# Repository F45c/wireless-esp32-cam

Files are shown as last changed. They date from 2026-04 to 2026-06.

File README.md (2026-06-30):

# Wireless Esp32-Camera using nRF24l01+

### What is it?

I'm building a wireless esp32 camera that uses the 2.4 GHZ RF chip nRF24l01+ to transmit the images over a greater distance than just WIFI. Using the Ebyte E01 2G4M27D Module achieving distances up to 3000 meters, I can receive images and change the resolution and quality of the captures from the receiver side.

### But Why?

My Wifi signal doesn't cover my entire property so I figured I will build a security camera that has a higher distance and can be placed on the edge where no normal camera would get a connection.
Also, out on my field, I can monitor all my stuff that's stored there from home and watch the animals walk around at night from a few hundred meters away.

### Build

These are the PCBs with the modules plugged into the PinSockets

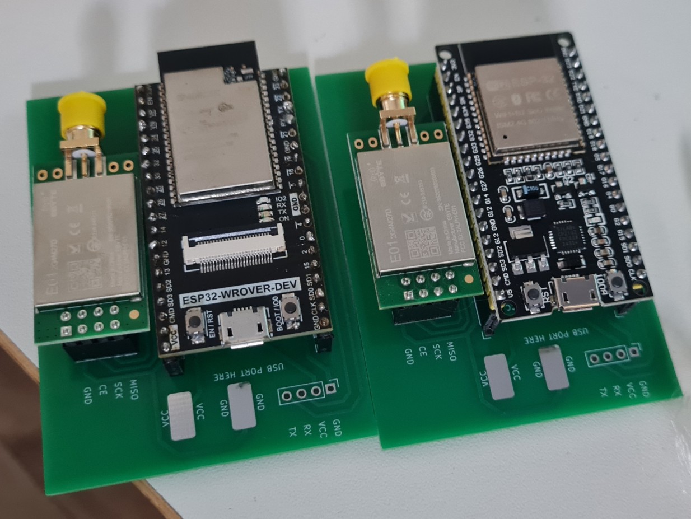
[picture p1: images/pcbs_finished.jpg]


This is the finished build with the camera and antennas and its working great!

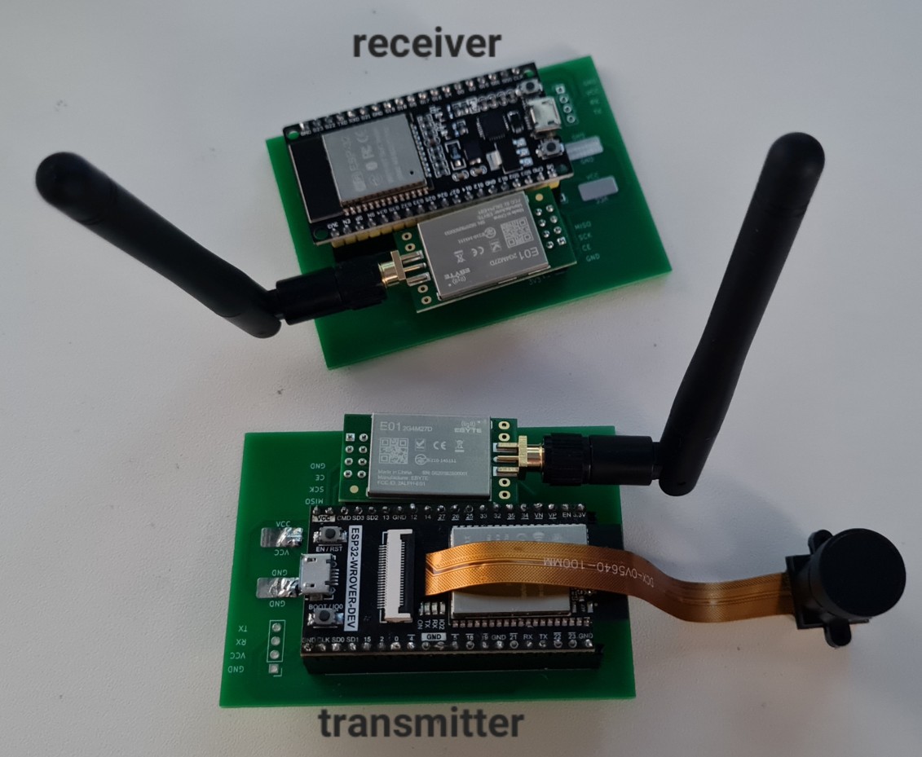
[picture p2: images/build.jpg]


The final build is way faster than the prototype and reaches a lot further even through walls.

### How it works

#### The Transmitter
The image is captured and divided into chunks of 32 bytes.

Then those chunks are split into 16 byte chunks for separately encrypting them using AES-128 (symmetric encryption).

Those chunks are transmitted on 2.4 ghz on a high channel like 74 preventing conflicts with wifi.

The nRF24 uses a proprietary protocol with GFSK (Gaussian Frequency Shift Keying).



#### The Receiver
The receiver separates the 32 byte chunks into 16 byte chunks for decryption following the transmission over Serial to the Computer.

The Computer runs a python script saving the data to an image file.

### 3D Model
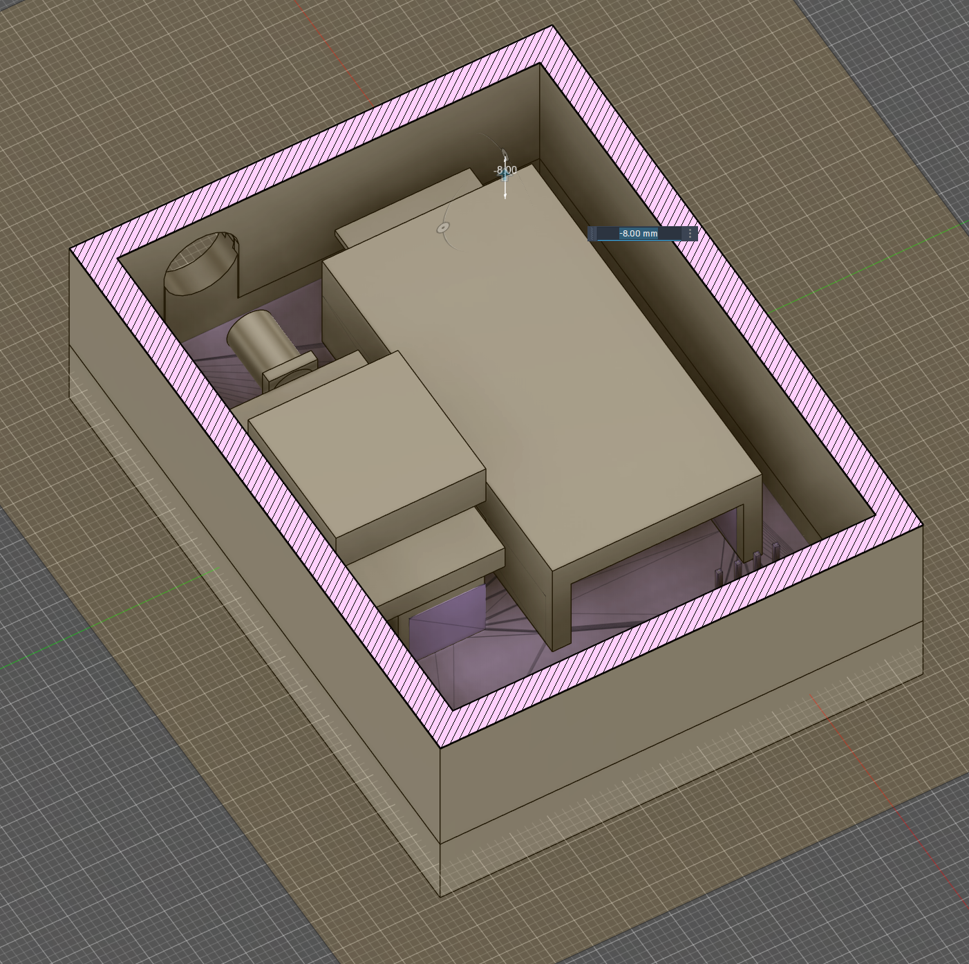
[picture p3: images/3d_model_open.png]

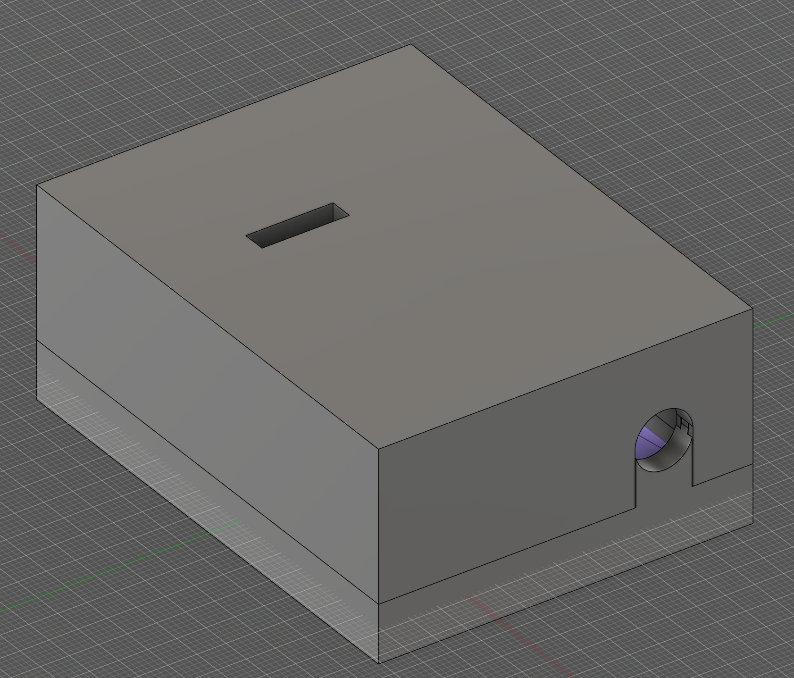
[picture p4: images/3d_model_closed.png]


### Prototyping

Using some cheaper modules and some perfboards, I made a prototype which I used to transmit and receive this image.

It's still low quality because of the bad prototype hardware. The highest distance I achieved with the prototype was ~100m line-of-sight and in another test, the signal was able to pass through two walls (steel-concrete 30cm) without much data loss.

These are the speeds the prototype achieved.

|Resolution & Quality|	Time|	FPS|
|---|----|----|
|160x120 + low jpeg quality| <1s|	~2.5|
320x240 + low jpeg quality|	~1.5s	| ~0.6|
480x320 + low jpeg quality|	~3s|	~0.3|
800x600 + little higher quality| ~15s| ~0.07|
1600x1200 + low jpeg quality|	~50s|	~0.02|

The final build with the PCB should be able to send higher quality and resolution images with less error rate and faster speeds. How fast the 2G4M27D is impossible to know but I'm assuming an increase of at least 30% in transmission speed. 

Since the datasheet claims a range of 5000m LOS, I'm assuming that the final build will achieve a functioning range of about 2500m LOS when placing the antennas correctly at a high place. This would be definitely enough for my use case.

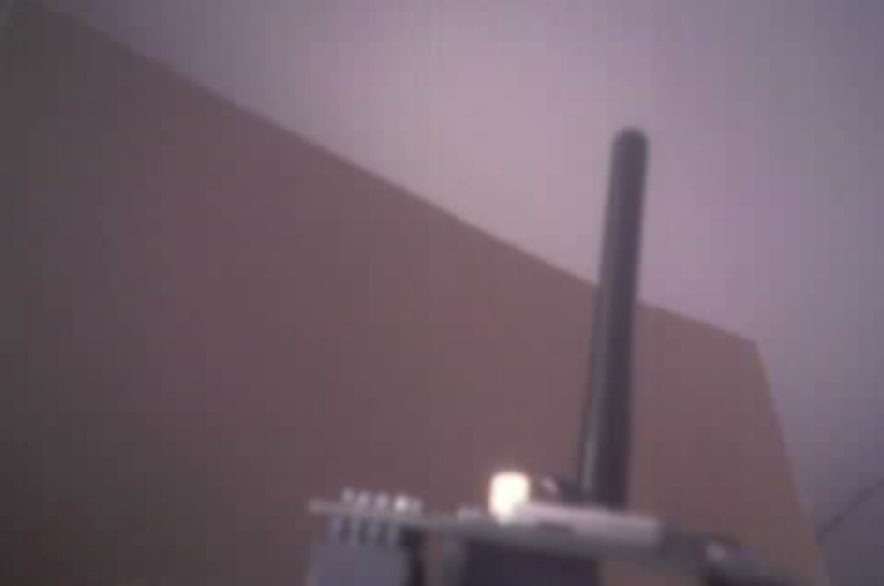
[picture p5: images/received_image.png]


### Schematic

I use PinSockets for both the Esp32 and the 2G4M27D and PinHeaders for the Esp32 UART interface. I added two pads for the 3.7v lithium ion battery and it's connected to the VCC pin of the Esp32 which is internally converted into 3.3v for the output pin.

This is the Pinout:
|Esp32|2G4M27D|
|-----|---|
|3V3|3V3|
|GND|GND|
|GPIO12|CE|
|GPIO33|CNS|
|GPIO14|SCK|
|GPIO25|MOSI|
|GPIO27|MISO|
|GPIO26|IRQ|

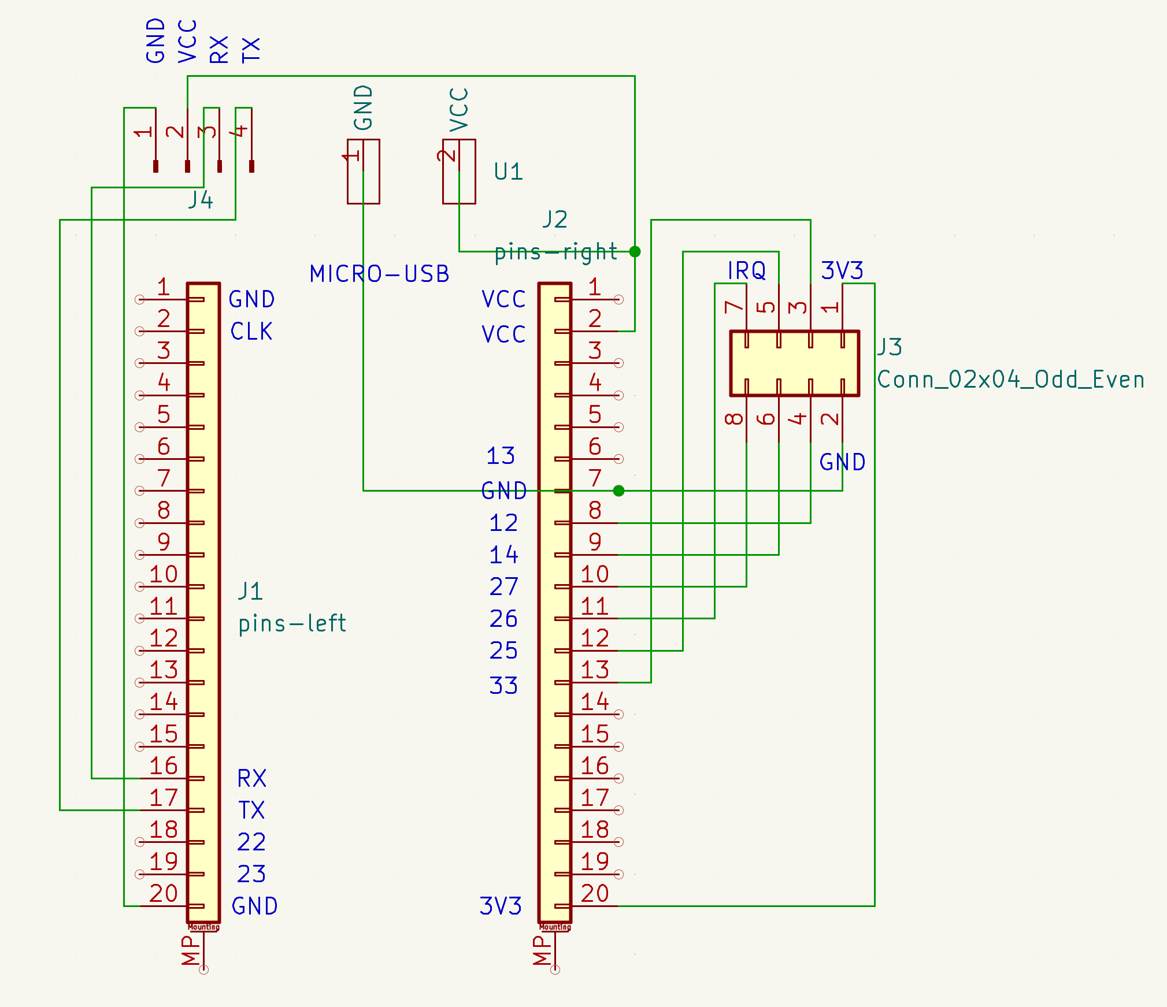
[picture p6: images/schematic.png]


### PCB Design
<p float="left">
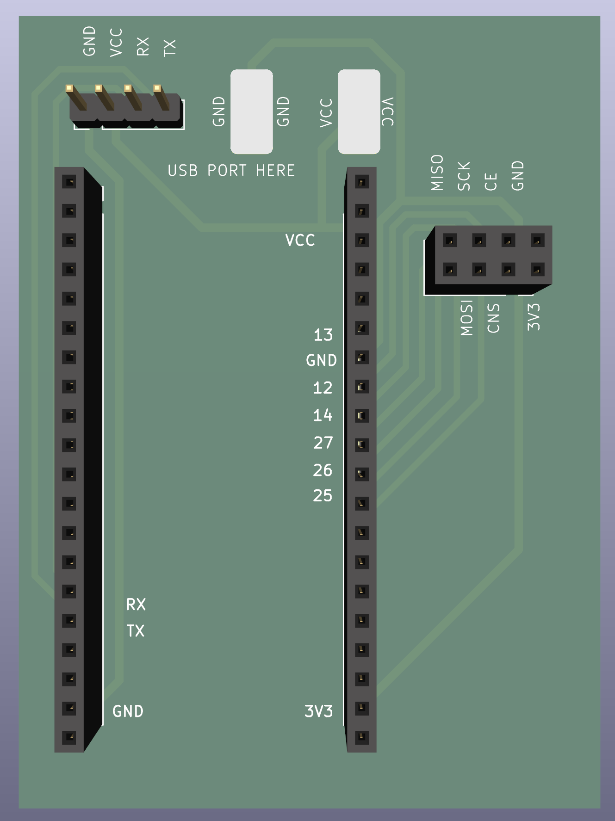
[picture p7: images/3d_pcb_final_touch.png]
  
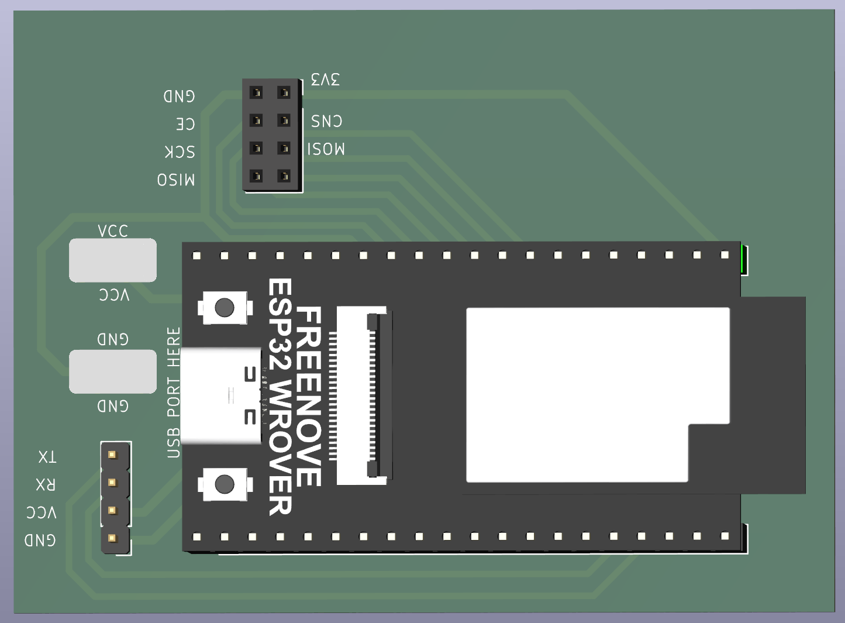
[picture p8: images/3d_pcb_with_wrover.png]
  
</p>

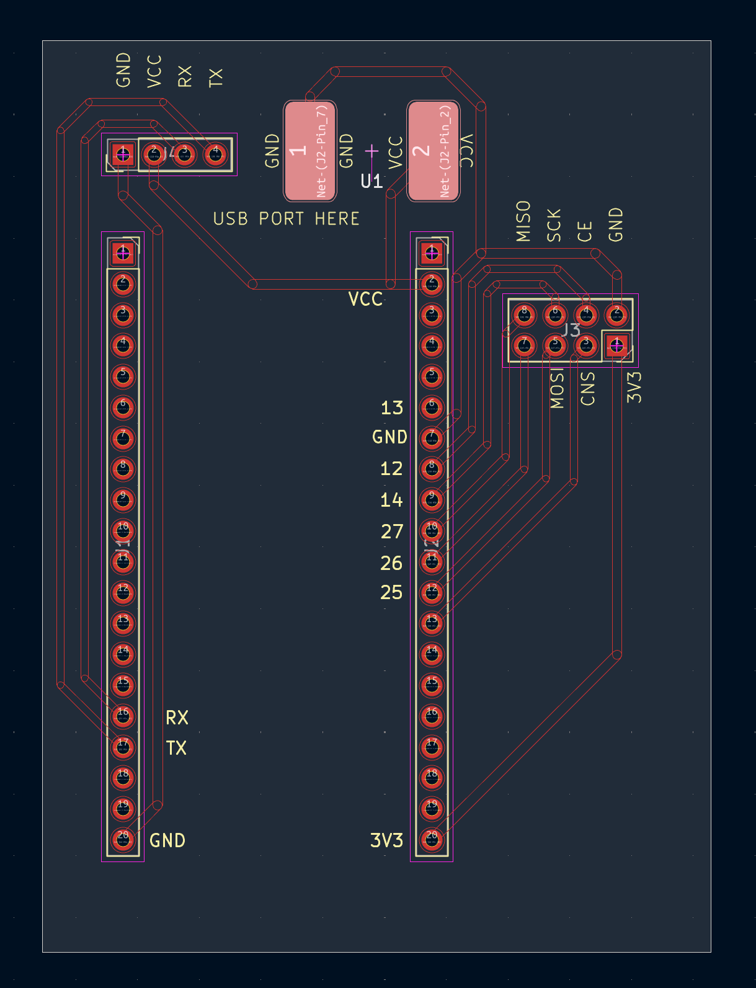
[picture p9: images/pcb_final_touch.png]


### BOM

|Name|Purpose|Quantity|Total Cost (USD)|Link|Distributor|
|----|---|---|---|---|---|
|3.7v LiPo battery|Battery for transmitter|1|21.18|https://www.conrad.de/de/p/akyga-lp675568-akkupack-x-spezial-akku-lipo-3-7-v-3500-mah-3385862.html|Conrad|
|PCB|PCB for both receiver and transmitter|1|5.5||JLCPCB|
|Esp32 38 pin|Receiver Esp32|1|5.73|https://de.aliexpress.com/item/1005006613312645.html|Aliexpress|
|Esp32 Wrover Cam OV5640|Capturing images and computing transmission|1|9|https://de.aliexpress.com/item/1005006705436186.html|Aliexpress|
|2 pieces Ebyte E01-2G4M27D|One for transmitter, one for receiver|1|11.9|https://de.aliexpress.com/item/1005003212341678.html|Aliexpress|

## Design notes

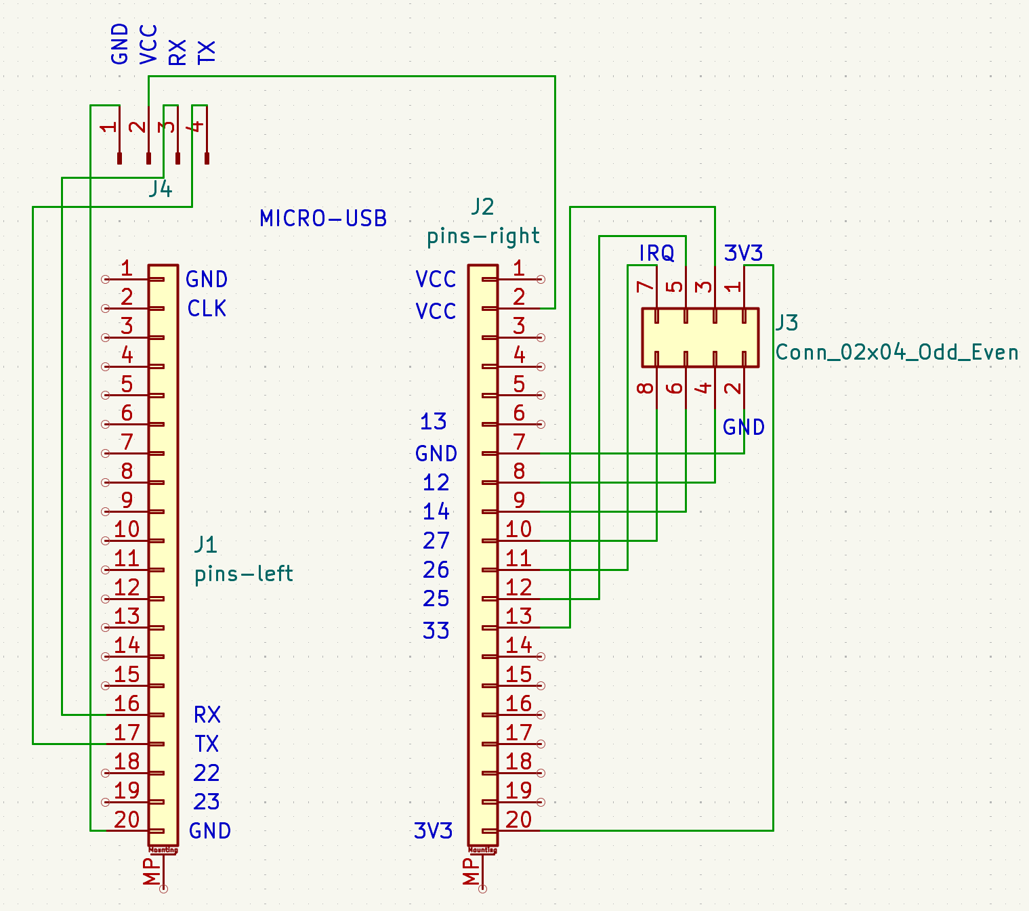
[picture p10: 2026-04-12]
images/schematic_final.png

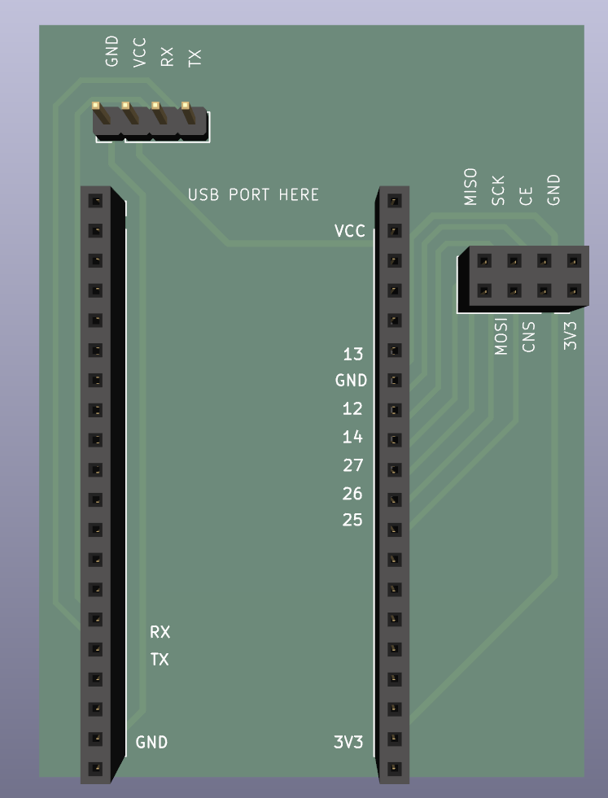
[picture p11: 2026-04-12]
images/3d_pcb.png

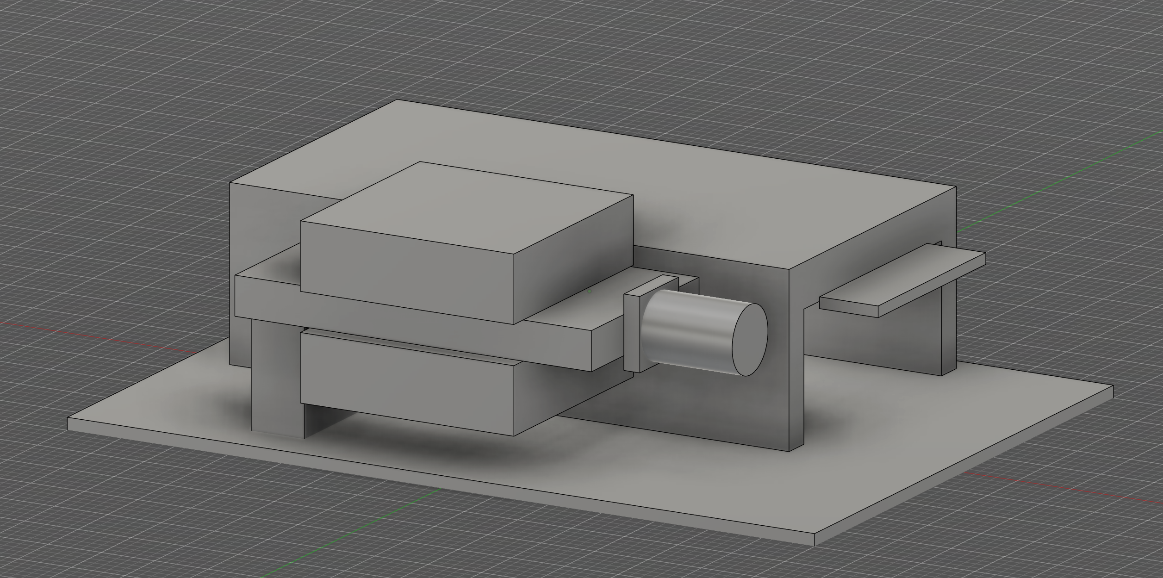
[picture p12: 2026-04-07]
images/perfboard_model_2.png

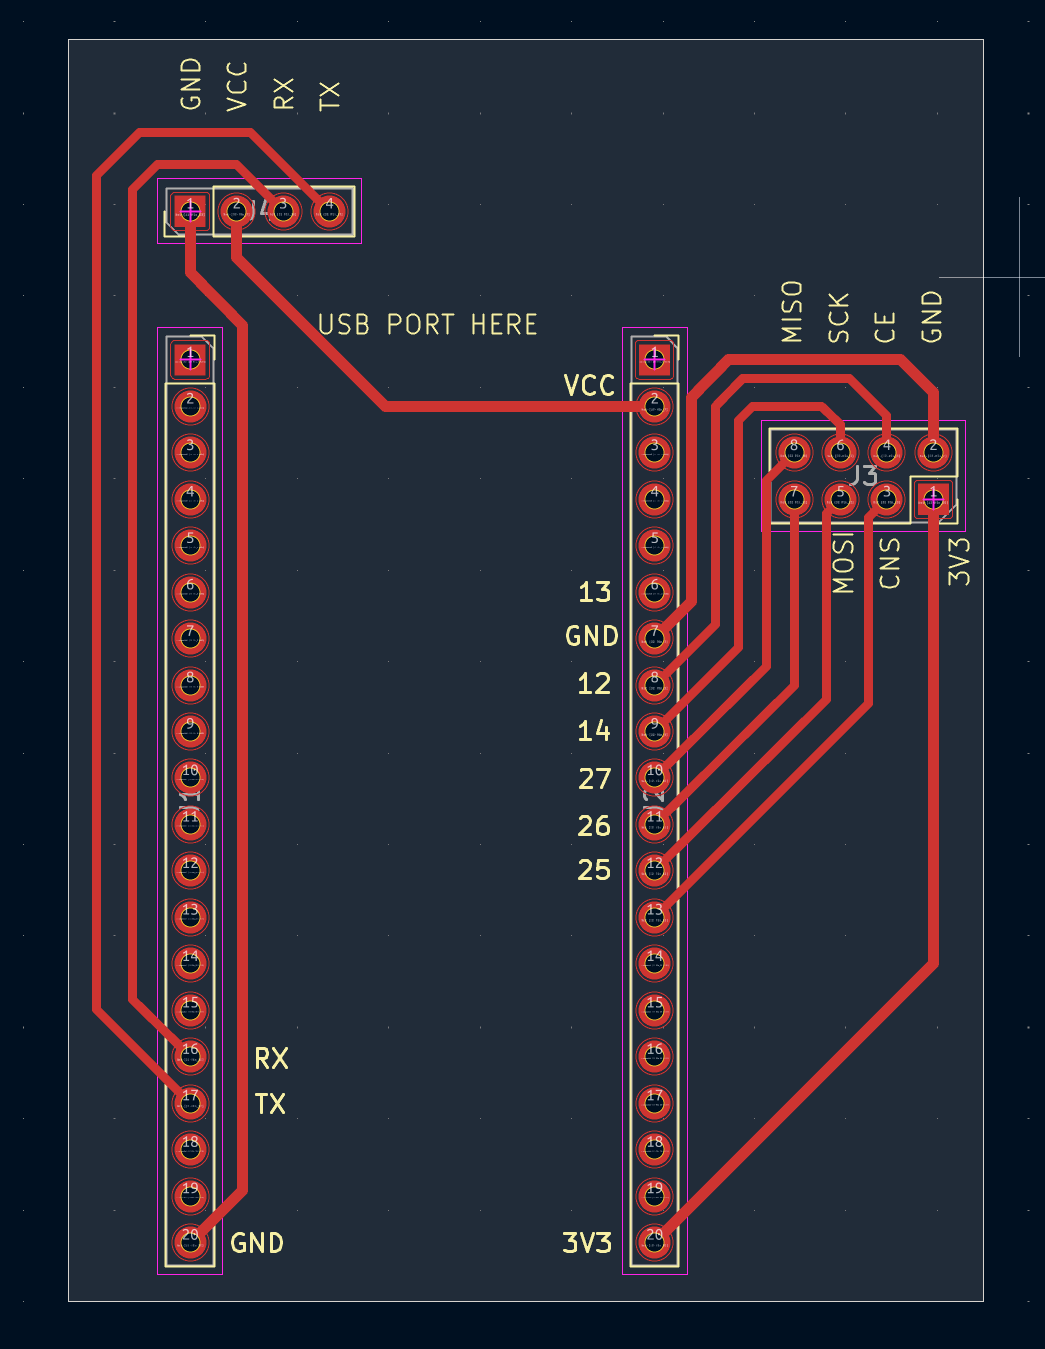
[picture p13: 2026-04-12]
images/pcb_final.png

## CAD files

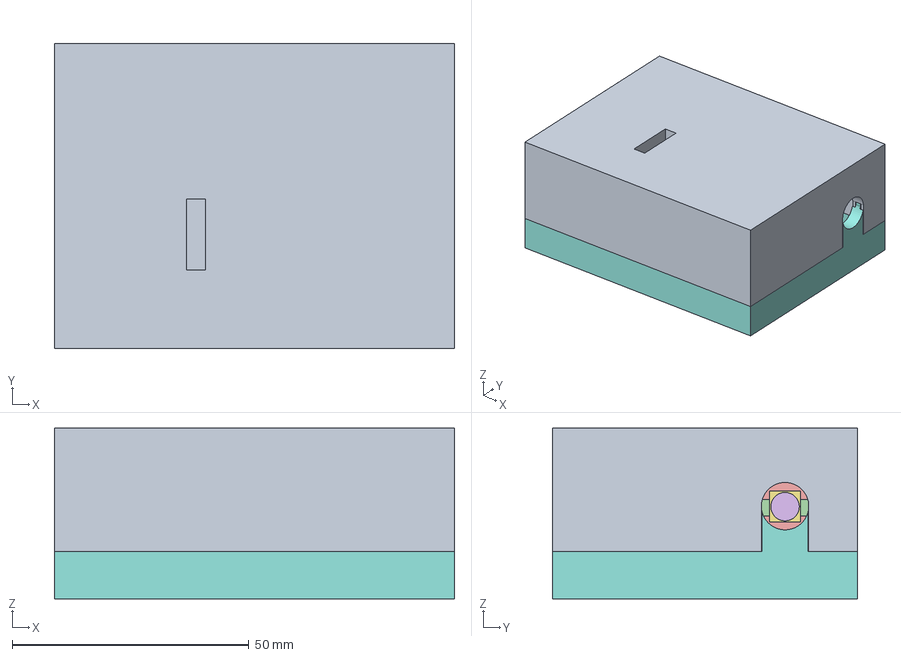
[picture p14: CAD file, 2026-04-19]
wireless_esp32_cam.step
84.4 x 64.4 x 36.0 mm

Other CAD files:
wireless_esp32_cam.stl

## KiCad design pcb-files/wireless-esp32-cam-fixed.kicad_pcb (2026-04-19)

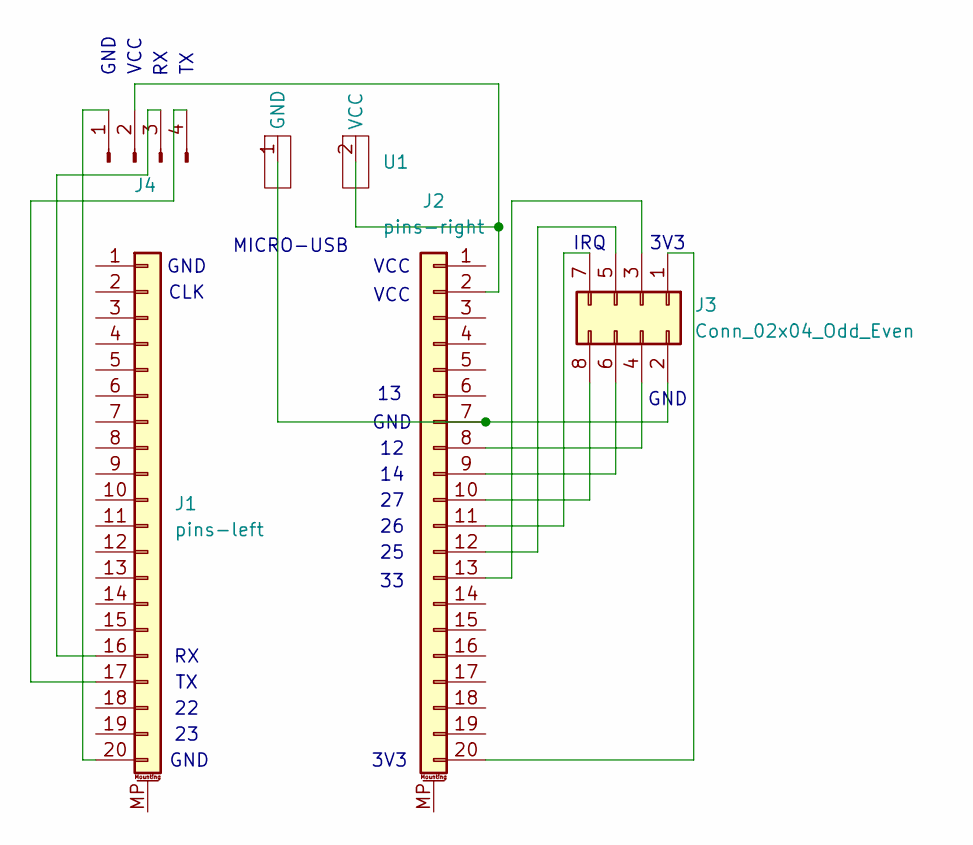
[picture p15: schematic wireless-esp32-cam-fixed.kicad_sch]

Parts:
J1: pins-left; PinSocket_1x20_P2.54mm_Vertical
J2: pins-right; PinSocket_1x20_P2.54mm_Vertical
J3: Conn_02x04_Odd_Even; PinSocket_2x04_P2.54mm_Vertical
J4: Conn_01x04_Pin; PinHeader_1x04_P2.54mm_Vertical
U1: solder-pad

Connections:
unnamed: J1.16, J4.3
unnamed: J1.17, J4.4
unnamed: J1.20, J4.1
unnamed: J2.2, J4.2, U1.2 (VCC)
unnamed: J2.7, J3.2, U1.1 (GND)
unnamed: J2.8, J3.4
unnamed: J2.9, J3.6
unnamed: J2.10, J3.8
unnamed: J2.11, J3.7
unnamed: J2.12, J3.5
unnamed: J2.13, J3.3
unnamed: J2.20, J3.1

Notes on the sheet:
GND
VCC
CLK
3V3
MICRO-USB
IRQ

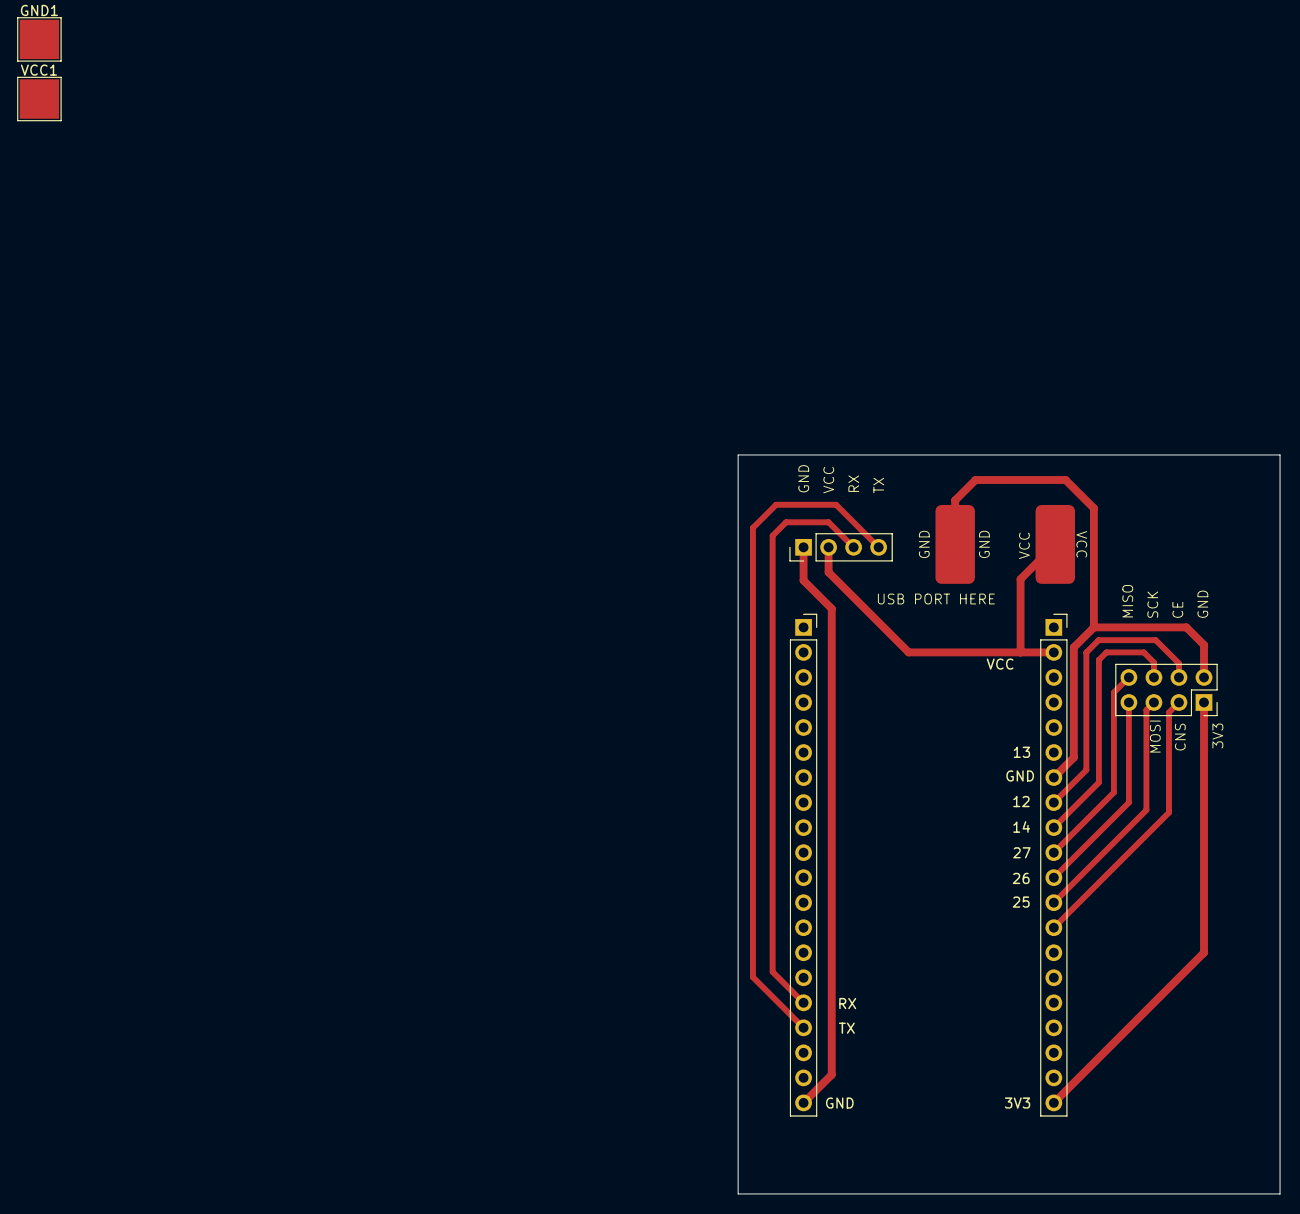
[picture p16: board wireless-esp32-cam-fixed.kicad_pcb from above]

Board: 2 copper layers, 55.0 x 75.0 mm, 7 parts (0 on the bottom side), 12 nets.

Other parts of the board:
GND1: MountingHole; TestPoint_Pad_4.0x4.0mm
VCC1: MountingHole; TestPoint_Pad_4.0x4.0mm

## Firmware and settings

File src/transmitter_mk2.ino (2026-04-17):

#include <SPI.h>
#include <nRF24L01.h>
#include <RF24.h>
#include "esp_camera.h"
#include <Crypto.h>
#include <AES.h>
#include <string.h>

#define PWDN_GPIO_NUM     -1
#define RESET_GPIO_NUM    -1
#define XCLK_GPIO_NUM      21
#define SIOD_GPIO_NUM      26
#define SIOC_GPIO_NUM      27

#define Y9_GPIO_NUM        35
#define Y8_GPIO_NUM        34
#define Y7_GPIO_NUM        39
#define Y6_GPIO_NUM        36
#define Y5_GPIO_NUM        19
#define Y4_GPIO_NUM        18
#define Y3_GPIO_NUM         5
#define Y2_GPIO_NUM         4
#define VSYNC_GPIO_NUM     25
#define HREF_GPIO_NUM      23
#define PCLK_GPIO_NUM      22

#define CE_PIN   2
#define CSN_PIN  15

RF24 radio(CE_PIN, CSN_PIN);
const byte addresses[][3] = {"sen", "rec"}; // 3 byte addresses for smaller transmission


void setupCamera() {
    camera_config_t config;
    config.ledc_channel = LEDC_CHANNEL_0;
    config.ledc_timer = LEDC_TIMER_0;
    config.pin_d0 = Y2_GPIO_NUM;
    config.pin_d1 = Y3_GPIO_NUM;
    config.pin_d2 = Y4_GPIO_NUM;
    config.pin_d3 = Y5_GPIO_NUM;
    config.pin_d4 = Y6_GPIO_NUM;
    config.pin_d5 = Y7_GPIO_NUM;
    config.pin_d6 = Y8_GPIO_NUM;
    config.pin_d7 = Y9_GPIO_NUM;
    config.pin_xclk = XCLK_GPIO_NUM;
    config.pin_pclk = PCLK_GPIO_NUM;
    config.pin_vsync = VSYNC_GPIO_NUM;
    config.pin_href = HREF_GPIO_NUM;
    config.pin_sscb_sda = SIOD_GPIO_NUM;
    config.pin_sscb_scl = SIOC_GPIO_NUM;
    config.pin_pwdn = PWDN_GPIO_NUM;
    config.pin_reset = RESET_GPIO_NUM;
    config.xclk_freq_hz = 20000000;
    config.pixel_format = PIXFORMAT_JPEG;

    config.frame_size = FRAMESIZE_UXGA; // somehow needs to be high to later use high res
    config.jpeg_quality = 2;
    config.fb_count = 2;


    esp_err_t err = esp_camera_init(&config);
    if (err != ESP_OK) {
        Serial.println("Camera init failed");
        while (true);
    }
}


framesize_t framesizes[] = {
    FRAMESIZE_QQVGA,   // 160x120
    FRAMESIZE_QVGA,    // 320x240
    FRAMESIZE_CIF,     // 352x288
    FRAMESIZE_HVGA,
    FRAMESIZE_VGA,     // 640x480
    FRAMESIZE_SVGA,    // 800x600
    FRAMESIZE_XGA,     // 1024x768
    FRAMESIZE_SXGA,    // 1280x1024
    FRAMESIZE_UXGA,    // 1600x1200
    FRAMESIZE_FHD,
    FRAMESIZE_QXGA,    // 2048x1536
    FRAMESIZE_QXGA
};
const int framesizesLength = sizeof(framesizes) / sizeof(framesizes[0]);

byte key[16] = { /* nothing to see here */ };


    AES128 aes128;

    void setup() {
        Serial.begin(115200);
        setupCamera();

        sensor_t *s = esp_camera_sensor_get();
        s->set_hmirror(s, 1);
        s->set_framesize(s, FRAMESIZE_QVGA);
        s->set_quality(s, 2);

        aes128.setKey(key, sizeof(key));

        SPI.begin(14, 12, 13, 15); // SCK, MISO, MOSI, SS
        SPI.setFrequency(4000000); // 4 mhz speed was working best
        if (!radio.begin()) {
            Serial.println("nRF24 init failed!");
            while (1);
        }

        radio.enableDynamicPayloads();     // for changing res and quality
        radio.enableAckPayload();

        radio.setPALevel(RF24_PA_MAX);     // max power
        radio.setDataRate(RF24_2MBPS);     // max speed
        radio.setRetries(15, 15);          // max retry count & delay
        radio.setAutoAck(true);            // keep ACKs for changing res and quality
        radio.setAddressWidth(3);          // smaller addresses
        radio.openWritingPipe(addresses[0]);
        radio.openReadingPipe(1, addresses[1]);
        radio.stopListening();

    }

    void loop() {
        camera_fb_t *fb = esp_camera_fb_get();
        if (!fb) {
            Serial.println("Camera capture failed");
            // reset settings to small images when big ones fail
            sensor_t *s = esp_camera_sensor_get();
            s->set_framesize(s, framesizes[0]);
            s->set_quality(s, 30);
            return;
        }

        size_t imgLen = fb->len;
        const uint8_t* imgData = fb->buf;

        Serial.print(imgLen);
        Serial.println(" bytes");


        for (size_t i = 0; i < imgLen; i += 32) {
            size_t chunkSize = 32;
            byte encrypted[chunkSize];
            aes128.encryptBlock(encrypted, imgData + i); // aes128 needs 16 bytes blocks
            aes128.encryptBlock(encrypted + 16, imgData + i + 16);
            radio.write(encrypted, chunkSize); // send two encrypted 16 byte blocks
            if(radio.available()) { // this is the dynamic ack payload
                // 1. byte res; 2. byte qualität
                uint8_t len = radio.getDynamicPayloadSize();
                uint8_t buf[len];
                radio.read(&buf, len);
                uint8_t newResolution = buf[0];
                uint8_t newQuality = buf[1];
                Serial.print("ACK: ");
                Serial.print(newResolution);
                Serial.print(" ");
                Serial.println(newQuality);
                sensor_t *s = esp_camera_sensor_get();
                if(newResolution >= 0 && newResolution < framesizesLength) s->set_framesize(s, framesizes[newResolution]);
                if(newQuality >= 2 && newQuality < 63) s->set_quality(s, newQuality);
                delayMicroseconds(1);
                break; // stop sending current image (because high res images takes a long time and it wouldn't switch until finished)
            }
        }
        byte end[] = { // last chunk of every image is custom end of image indicator
            '=','=','=','=', '=','=','=','=',
            '=','=','=','=', '=','=','=','=',
            '=','=','=','=', '=','=','=','=',
            '=','=','=','=', '=','=','=','='};
            byte encrypted[sizeof(end)];
            aes128.encryptBlock(encrypted, end);
            aes128.encryptBlock(encrypted + 16, end + 16);
            radio.write(encrypted, sizeof(encrypted));
            esp_camera_fb_return(fb); // free frame buffer
            return;
    }

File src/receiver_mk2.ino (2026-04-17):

#include <SPI.h>
#include <RF24.h>
#include <Crypto.h>
#include <AES.h>
#include <string.h>

#define CE_PIN 4
#define CSN_PIN 5

    byte key[16] = { /* nothing to see here */ };


    RF24 radio(CE_PIN, CSN_PIN);
    const byte addresses[][6] = {"sen", "rec"};

    AES128 aes128;

    bool receiving = false;
    unsigned long lastPacketTime = 0;
    const int TIMEOUT_MS = 2000;
    byte ackPacket[2];
    void setup() {
        Serial.begin(115200);
        delay(2000);

        aes128.setKey(key, sizeof(key));

        Serial.println("Starting nRF24 Receiver...");
        Serial.print("&&&");
        SPI.begin();
        SPI.setFrequency(4000000); //4mhz spi speed
        if (!radio.begin()) {
            Serial.println("nRF24 init failed!");
            while (1);
        }

        radio.enableDynamicPayloads();  // for changing resolution etc.
        radio.enableAckPayload();

        radio.setPALevel(RF24_PA_MAX);     // max power
        radio.setDataRate(RF24_2MBPS);     // max speed
        radio.setRetries(15, 15);          // max retry count & delay
        radio.setAutoAck(true);            // keep ACKs
        radio.setAddressWidth(3);          // address größe auf 3 bytes, wird bei jedem packet mit gesendet
        radio.openWritingPipe(addresses[1]);
        radio.openReadingPipe(1, addresses[0]);

        radio.writeAckPayload(1, &ackPacket, sizeof(ackPacket)); // only works if called once in setup somehow
        radio.startListening();
    }
    int chunkSize = 32;
    void loop() {

        if(Serial.available()) { // get new res and quality over serial
            byte res = Serial.read();   // resolution (0-11)
            byte qual = Serial.read();  // quality (0-62)

            ackPacket[0] = res;
            ackPacket[1] = qual;
            radio.writeAckPayload(1, &ackPacket, sizeof(ackPacket));
        }

        if (radio.available()) {
            receiving = true;
            uint8_t packet[chunkSize];
            radio.read(&packet, sizeof(packet));
            byte decrypted[chunkSize];
            aes128.decryptBlock(decrypted,packet);
            aes128.decryptBlock(decrypted + 16,packet + 16);
            Serial.write(decrypted, sizeof(decrypted));
            lastPacketTime = millis();
            delayMicroseconds(1);
        }

        if (receiving && millis() - lastPacketTime > TIMEOUT_MS) {
            Serial.print("===");
            receiving = false;
            delayMicroseconds(2);
        }
    }

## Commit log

2026-04-12 added schematic, pcb and 3d model images
2026-04-19 added step file and 3d model
    [wireless_esp32_cam.step, wireless_esp32_cam.stl]
2026-04-19 added pcb files
    [wireless-esp32-cam-fixed.kicad_pcb, wireless-esp32-cam-fixed.kicad_sch]
2026-04-19 added final pcb design images
2026-04-19 added bom
    [BOM.csv]
2026-04-19 added battery to bom
    [BOM.csv]
2026-05-06 added pcb model with esp32 wrover
2026-05-14 added schematic image
2026-05-14 Added Prototype Testing Data and Schematic explanation
